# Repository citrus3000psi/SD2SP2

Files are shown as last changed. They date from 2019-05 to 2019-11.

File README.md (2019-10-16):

# SD2SP2

This PCB allows a MicroSD card to adapted into the serial port2 of the gamecube.

The PCB must be ordered in 1.2mm thickness. Surface finish must be ENIG at minimum.  I recommened https://jlcpcb.com for PCB production

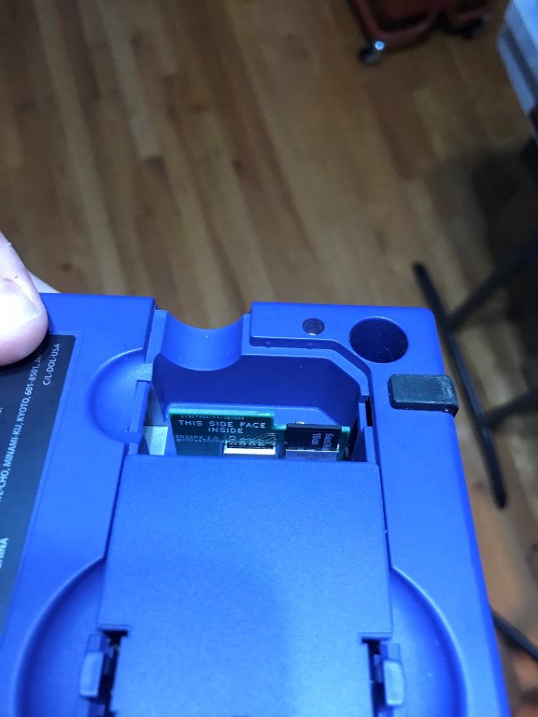
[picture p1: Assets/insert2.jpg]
The serial port SD adapter installed into the bottom of a GameCube SD2SP2


BOM:  

C1: 0805 22u Capactior (10V Min) - DigiKey Part# 	1276-6780-1-ND  

J1: MicroSD Slot - DigiKey Part# WM6825CT-ND  

Unassembled kits will be available for purchase at my webstore soon: https://shop.dansprojects.com

Special thanks to:  
 * MockyLock for the idea  
 * Extrems & emu_kidid for doing the real work needed to make this possible

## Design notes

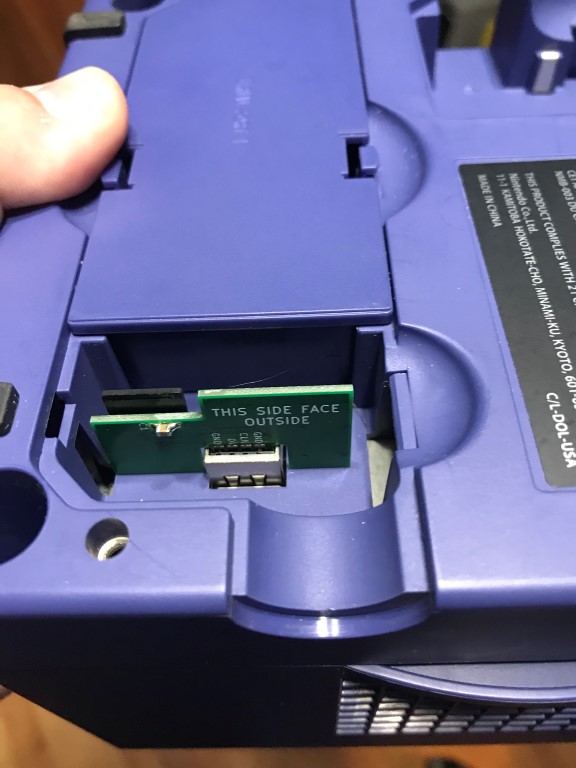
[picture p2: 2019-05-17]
Assets/insert.jpg

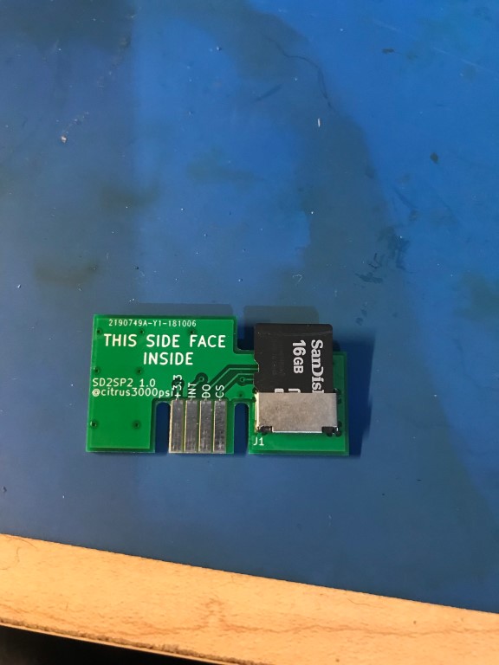
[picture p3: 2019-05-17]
Assets/top.jpg

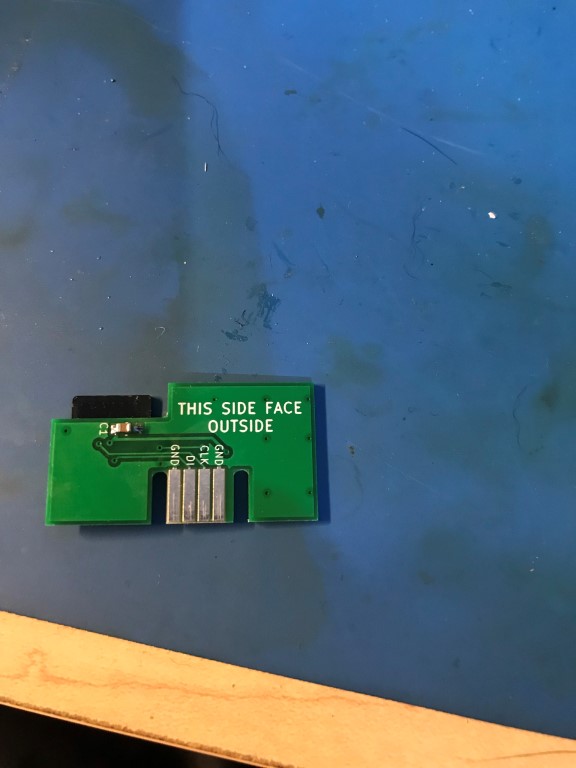
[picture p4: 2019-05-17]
Assets/bottom.jpg

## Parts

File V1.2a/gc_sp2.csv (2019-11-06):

Reference | Quantity | Value | Footprint | Datasheet
C1 | 1 | .1 | Capacitors_SMD:C_0805_HandSoldering | ~
J1 | 1 | Micro_SD_Card | gc_sp2:1050270001 | http://katalog.we-online.de/em/datasheet/693072010801.pdf
P1 | 1 | SerialPort | gc_sp2:SP2_FootPrint

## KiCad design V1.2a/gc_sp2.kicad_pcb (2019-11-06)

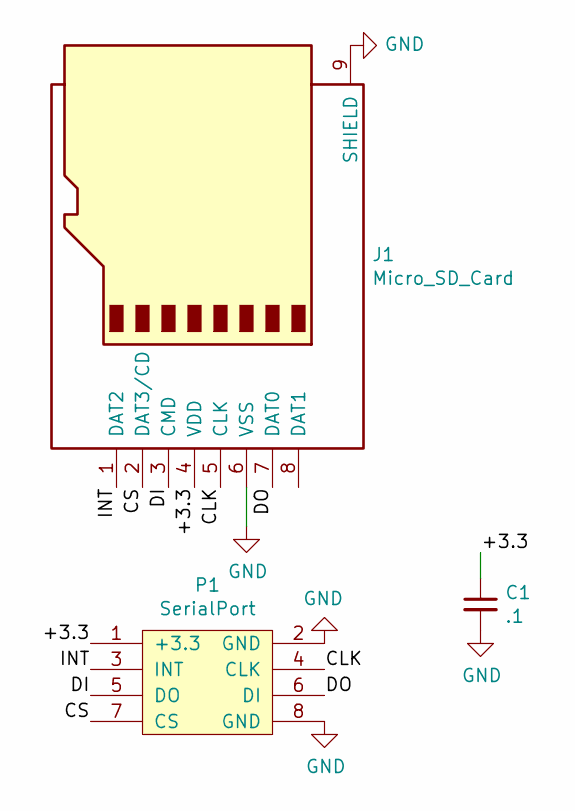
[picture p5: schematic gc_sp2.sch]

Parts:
C1: .1; C_0805_HandSoldering
J1: Micro_SD_Card; 1050270001
P1: SerialPort; SP2_FootPrint

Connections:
/+3.3: C1.1, J1.4 (VDD), P1.1 (+3.3)
/CLK: J1.5 (CLK), P1.4 (CLK)
/CS: J1.2 (DAT3/CD), P1.7 (CS)
/DI: J1.3 (CMD), P1.5 (DO)
/DO: J1.7 (DAT0), P1.6 (DI)
/INT: J1.1 (DAT2), P1.3 (INT)
GND: C1.2, J1.6 (VSS), J1.9 (SHIELD), P1.2 (GND), P1.8 (GND)

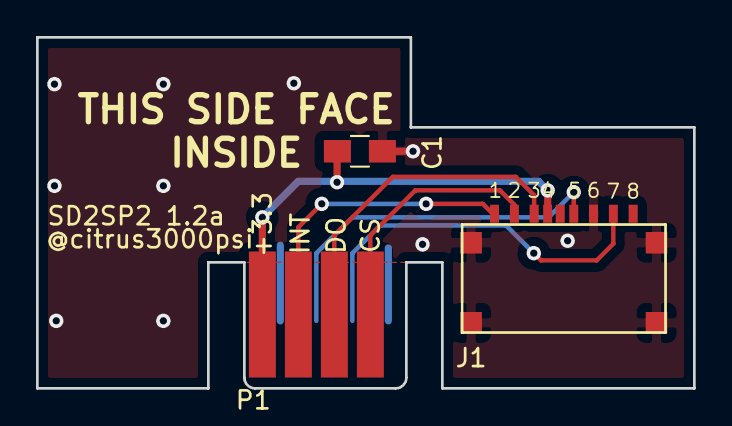
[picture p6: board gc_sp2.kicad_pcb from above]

Board: 2 copper layers, 36.5 x 19.5 mm, 3 parts (0 on the bottom side), 7 nets.

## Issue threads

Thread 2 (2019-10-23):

Full-size SD version?

iaros, 2019-10-23:
Hello, and thank you for such an interesting concept and implementation to use the NGC's second port.

Would it be possible to adapt this solution for a full-sized SD card (because many people who would switch from wii-sd already have full-size cards which they already tested to work with swiss)?

Regards

citrus3000psi, 2019-10-23:
In its current form no, perhaps with a multi piece pcb you could some how make it work.  But would be a manufacturing nightmare.

Closed 2019-10-23.

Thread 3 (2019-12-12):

Capacitor Polarisation

davidsomen, 2019-12-12:
It looks as though the capacitor you've specified is unpolarised. Would it possible to use a polarised capacitor of the same specification in it's place? And if so which polarity?

davidsomen, 2019-12-17:
I have it orientated as + on the left side. I've no idea if the circuit will only ever apply voltage in that polarity but it seems to work.

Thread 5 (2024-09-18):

Any particular reason for 10V Min capacitor?

Anakiev2, 2024-09-18:
Hi, why 10v minimum for 3.3v rail? I can only find 6.3v 22uF capacitors. I am think it will be fine but I am not sure.
Thanks!

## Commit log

2019-05-17 Added Design Files
    [gc_sp2.kicad_pcb, gc_sp2.sch]
2019-05-17 Updated Design
    [gc_sp2.kicad_pcb]
2019-05-17 Added Gerber
    [gc_sp2-B_Cu.gbl, gc_sp2-B_Mask.gbs, gc_sp2-B_SilkS.gbo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]
2019-11-06 1.2a moved cap to sd side for easier PCBA
    [gc_sp2-B_Cu.gbl, gc_sp2-B_Mask.gbs, gc_sp2-B_SilkS.gbo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]
